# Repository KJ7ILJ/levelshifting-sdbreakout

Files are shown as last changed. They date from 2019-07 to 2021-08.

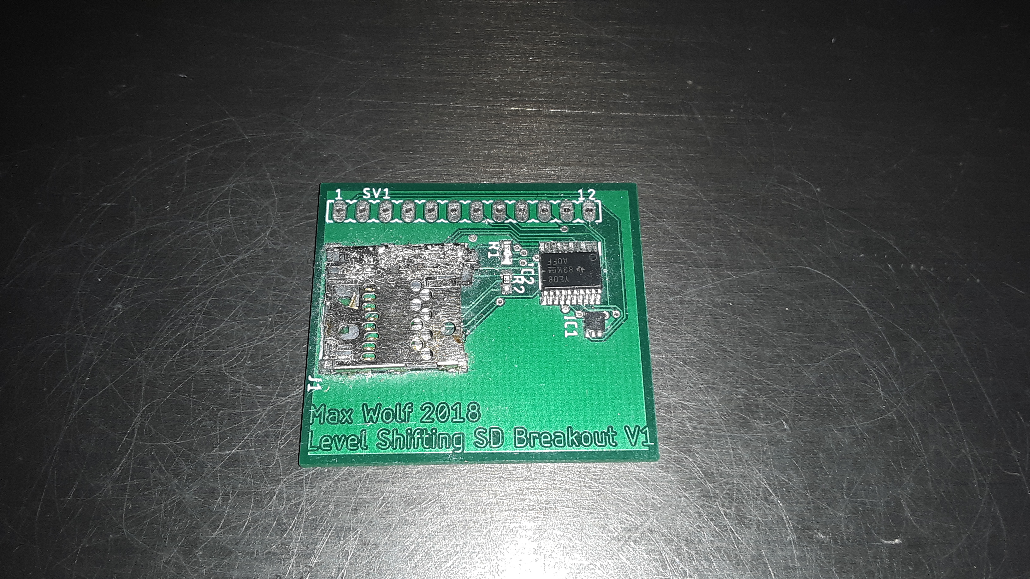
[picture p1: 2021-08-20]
ls_sd_breakout1.jpg

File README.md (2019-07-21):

# levelshifting-sdbreakout
A level shifting SD breakout board compatible with 3.3V to 5V logic.

-CAMOutputs: Current Gerber and .XLN files for PCB production <br/>
-All .brd and .sch files are Eagle board and schematic files, respectively <br/>
-partslist.txt contains the part numbers and quantities for every component needed to build one of these breakout boards <br/>

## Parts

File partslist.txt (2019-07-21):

LS-SD Breakout V1 Parts List:
	-QTY-PRT
	-1-TLV75533PDRVR
	-1-12PIN-FHEADER
	-1-TXB0108PWR
	-2-AC0603FR-104K75L
	-1-2201778-1

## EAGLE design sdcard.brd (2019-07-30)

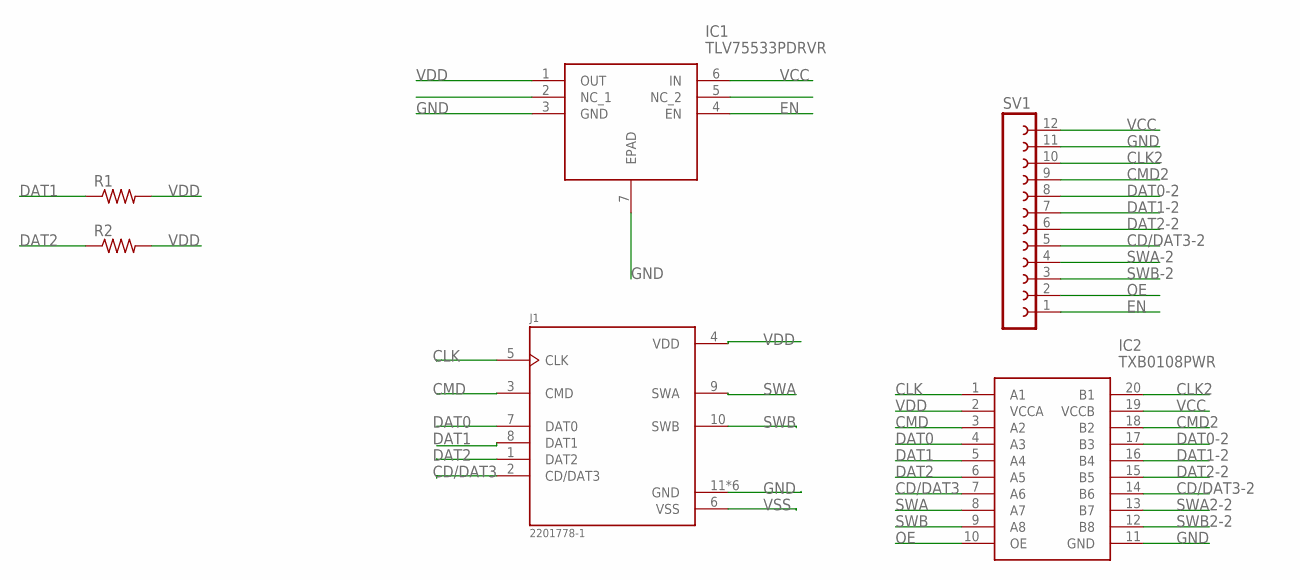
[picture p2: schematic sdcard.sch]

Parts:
IC1: TLV75533PDRVR; SON65P200X200X80-7N
IC2: TXB0108PWR; SOP65P640X120-20N
J1: 2201778-1; TE_2201778-1
R1, R2: R-US_R0603; R0603
SV1: FE12-1; FE12

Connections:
CD/DAT3: IC2.7 (A6), J1.2 (CD/DAT3)
CD/DAT3-2: IC2.14 (B6), SV1.5
CLK: IC2.1 (A1), J1.5 (CLK)
CLK2: IC2.20 (B1), SV1.10
CMD: IC2.3 (A2), J1.3 (CMD)
CMD2: IC2.18 (B2), SV1.9
DAT0: IC2.4 (A3), J1.7 (DAT0)
DAT0-2: IC2.17 (B3), SV1.8
DAT1: IC2.5 (A4), J1.8 (DAT1), R1.1
DAT1-2: IC2.16 (B4), SV1.7
DAT2: IC2.6 (A5), J1.1 (DAT2), R2.1
DAT2-2: IC2.15 (B5), SV1.6
EN: IC1.4 (EN), SV1.1
GND: IC1.3 (GND), IC1.7 (EPAD), IC2.11 (GND), J1.11 (GND), J1.12 (GND), J1.13 (GND), J1.14 (GND), J1.15 (GND), J1.16 (GND), SV1.11
OE: IC2.10 (OE), SV1.2
SWA: IC2.8 (A7), J1.9 (SWA)
SWA2-2: IC2.13 (B7)
SWA-2: SV1.4
SWB: IC2.9 (A8), J1.10 (SWB)
SWB2-2: IC2.12 (B8)
SWB-2: SV1.3
VCC: IC1.6 (IN), IC2.19 (VCCB), SV1.12
VDD: IC1.1 (OUT), IC2.2 (VCCA), J1.4 (VDD), R1.2, R2.2
VSS: J1.6 (VSS)

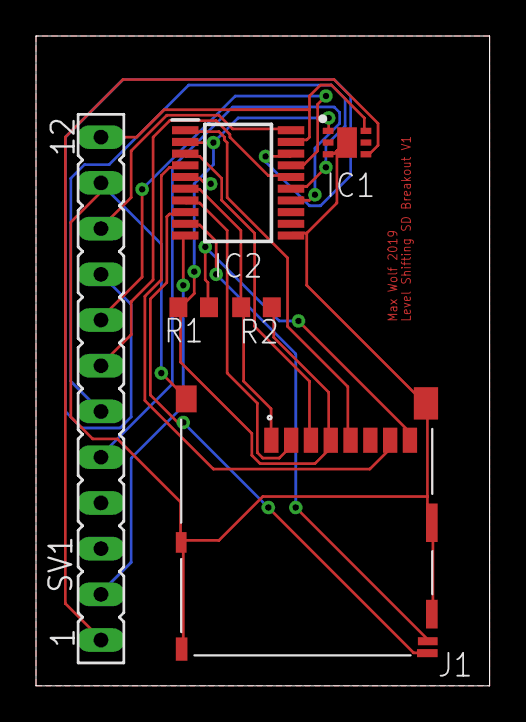
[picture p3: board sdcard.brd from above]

Board: 2 copper layers, 25.2 x 36.1 mm, 6 parts (0 on the bottom side), 19 nets.
